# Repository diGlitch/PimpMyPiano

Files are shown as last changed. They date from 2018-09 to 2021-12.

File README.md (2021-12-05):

# PimpMyPiano
## Mbed based interface between Fatar TP44GH keybed and the midi world
---------------------------------------------------------------------------------------------------
Some day the controller board of my StudioLogic SL990Pro stopped working. Instead of buying a whole new masterkeybard I though "why not building one my self and reusing the high quality Fata TP44GH keybed in there". What had to be done was to read out the double button matrix (two buttons/sensors for each note), meassuring the time between two button presses and convert this data into midi commands after about a year I ended up with a Mbed based interface between a Fatar TP44GH keybed and the midi world.

## How to make it work || Underconstruction
These instructions will get you a copy of the project up and running on your local machine for development and testing purposes. See deployment for notes on how to deploy the project on a live system.

There are two parts: The software and the hardware.

### Prerequisites || Underconstruction
What things you need to install the software and how to install them

You will need ...:
* an ARM MBED ready board. I used the [NUCLEO-F411RE](https://os.mbed.com/platforms/ST-Nucleo-F411RE/) from ST. I guess the 100Mhz are a bit overkill so assume that something slower with similar pinout would do.
* hardware that connects the Nucleo with the Button Matrix of the piano. See Hardware folder for schematic and other hardware related details such as a part list.
* software that runs on the Nucleo. You can find the [PlatformIO](http://platformio.org) project in the src folder. Just clone the repo or download scr folder as ZIP and open "PimpMyPiano" folder in platformIO.

## Build With
* [MBED OS](https://www.mbed.com/en/platform/mbed-os/)
* [PlatformIO](http://platformio.org) extension for [VSCode](https://code.visualstudio.com/)

## Contributing || Underconstruction

### What is there to be improved
* Overall code base in terms of speed

## Authors
* **Jeremy Constantin Börker** - *Initial and so far all the work* - [diGlitch](https://github.com/diGlitch)

## License
This project is licensed under the GNU General Public License v3.0 - see the [LICENSE](LICENSE) file for details

## Acknowledgments
* Francois Best's Mbed MIDI Library for Arduino ported by Hiroshi Suga
* YoongHM's Mbed shift register library
* Processing for the mapping formular

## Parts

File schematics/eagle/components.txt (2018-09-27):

Main Components:
Fatar TP44GH
ST NUCLEO-F411RE
2x Shift Register SN74HC595N
Resistor
Resistor
Resistor

Others
DIN 5 Pin MIDI Socket

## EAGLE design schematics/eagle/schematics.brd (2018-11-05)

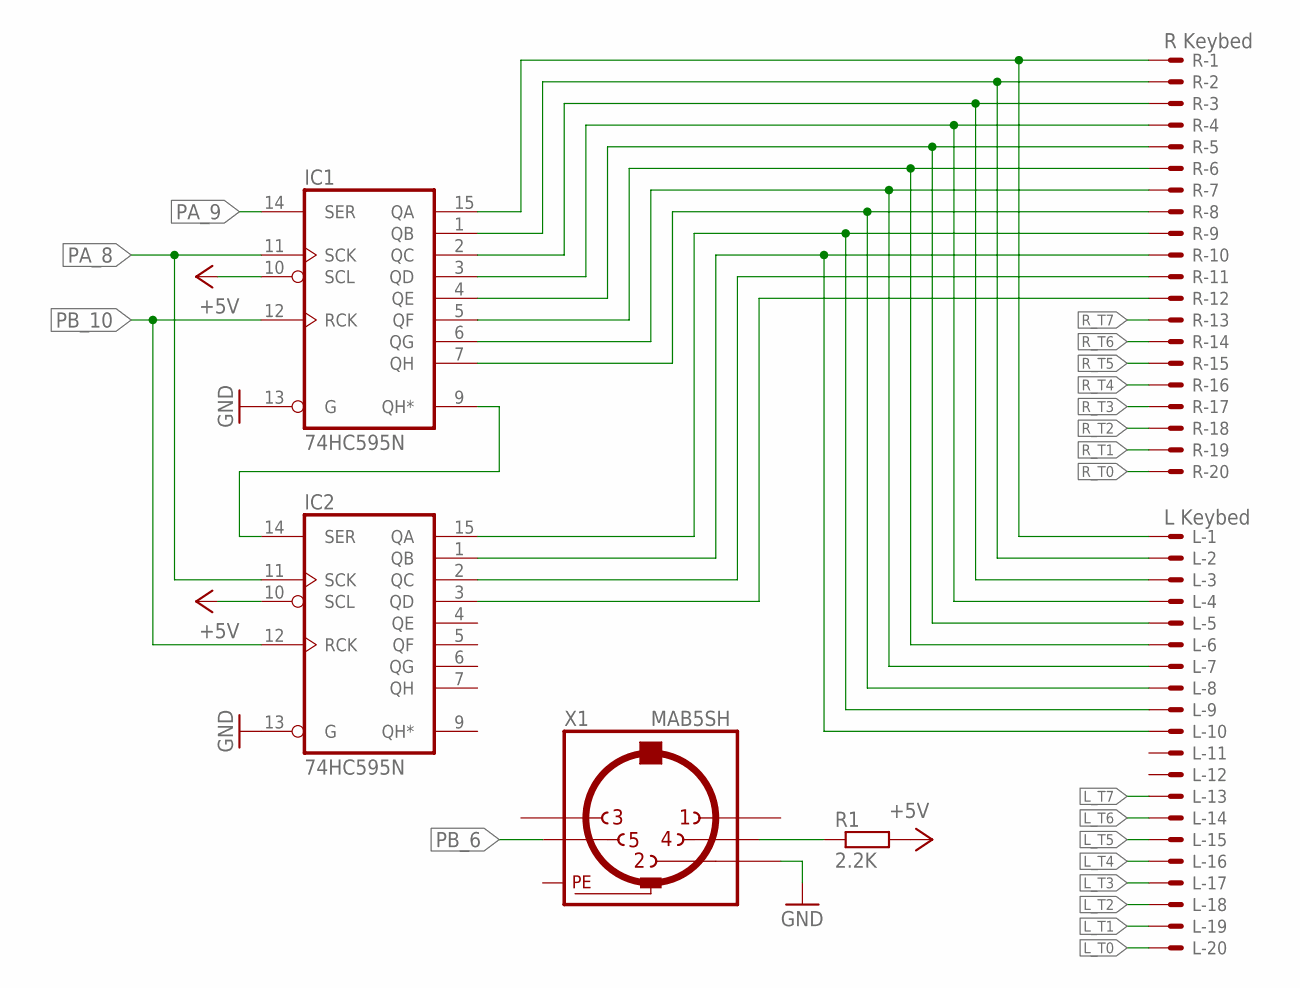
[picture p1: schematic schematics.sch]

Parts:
IC1, IC2: 74HC595N; DIL16
L: L Keybed; 5566-20
R: R Keybed; 5566-20
R1: 2.2K; 0207/10
X1: MAB5SH

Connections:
+5V: IC1.10 (SCL), IC2.10 (SCL), R1.2
GND: IC1.8 (GND), IC1.13 (G), IC2.8 (GND), IC2.13 (G), X1.2
L_T0: L.20
L_T1: L.19
L_T2: L.18
L_T3: L.17
L_T4: L.16
L_T5: L.15
L_T6: L.14
L_T7: L.13
unnamed: IC1.15 (QA), L.1, R.1
unnamed: IC1.1 (QB), L.2, R.2
unnamed: IC1.2 (QC), L.3, R.3
unnamed: IC1.3 (QD), L.4, R.4
unnamed: IC1.4 (QE), L.5, R.5
unnamed: IC1.5 (QF), L.6, R.6
unnamed: IC1.6 (QG), L.7, R.7
unnamed: IC1.7 (QH), L.8, R.8
unnamed: IC2.15 (QA), L.9, R.9
unnamed: IC2.1 (QB), L.10, R.10
unnamed: IC2.2 (QC), R.11
unnamed: IC2.3 (QD), R.12
unnamed: IC1.9 (QH*), IC2.14 (SER)
unnamed: R1.1, X1.4
PA_8: IC1.12 (RCK), IC2.12 (RCK)
PA_9: IC1.14 (SER)
PB_6: X1.5
PB_10: IC1.11 (SCK), IC2.11 (SCK)
PE: X1.PE, X1.PE@ (PE)
R_T0: R.20
R_T1: R.19
R_T2: R.18
R_T3: R.17
R_T4: R.16
R_T5: R.15
R_T6: R.14
R_T7: R.13
VCC: IC1.16 (VCC), IC2.16 (VCC)

Board: 2 copper layers, 6 parts (0 on the bottom side), 20 nets, no tracks yet.

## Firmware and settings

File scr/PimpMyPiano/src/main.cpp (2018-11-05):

/*
<PimpMyPiano - Mbed based interface between a Fatar TP44GH keybed and the midi world.>
Copyright (C) 2018  Jeremy Constantin Börker aka diGlitch

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
You should have received a copy of the GNU General Public License
along with this program.  If not, see <https://www.gnu.org/licenses/>.
*/

// Special Thanks to: Johannes Löwe, Codruta Lugoj


#include "mbed.h"
#include "MIDI.h"
#include <cmath>
#include "PianoKey.h"
#include "ShiftReg.h"

MIDI midi(PB_6, PA_10); // Serail2
Serial pc(USBTX, USBRX); // tx, rx
InterruptIn btn(USER_BUTTON);
DigitalOut led(LED1);

ShiftReg   HC595(PA_9, PA_8, PB_10);
int regCounter = 0;

DigitalIn tl_1(PC_10);
DigitalIn tl_2(PC_12);
DigitalIn tl_3(PA_13);
DigitalIn tl_4(PA_14);
DigitalIn tl_5(PA_15);
DigitalIn tl_6(PB_7);
DigitalIn tl_7(PC_2);
DigitalIn tl_8(PC_3);

DigitalIn tr_1(PC_11);
DigitalIn tr_2(PD_2);
DigitalIn tr_3(PA_0);
DigitalIn tr_4(PA_1);
DigitalIn tr_5(PA_4);
DigitalIn tr_6(PB_0);
DigitalIn tr_7(PC_1);
DigitalIn tr_8(PC_0);

const int DELAY = 05; // time delay to set output register

// set t pins as pullup inputs.
// set mk5 and br5 to 0 to read it t
PianoKey A_0(21);
PianoKey Asharp_0(22);
PianoKey B_0(23);
PianoKey C_1(24);
PianoKey Csharp_1(25);
PianoKey D_1(26);
PianoKey Dsharp_1(27);
PianoKey E_1(28);
PianoKey F_1(29);
PianoKey Fsharp_1(30);
PianoKey G_1(31);
PianoKey Gsharp_1(32);
PianoKey A_1(33);
PianoKey Asharp_1(34);
PianoKey B_1(35);
PianoKey C_2(36);
PianoKey Csharp_2(37);
PianoKey D_2(38);
PianoKey Dsharp_2(39);
PianoKey E_2(40);
PianoKey F_2(41);
PianoKey Fsharp_2(42);
PianoKey G_2(43);
PianoKey Gsharp_2(44);
PianoKey A_2(45);
PianoKey Asharp_2(46);
PianoKey B_2(47);
PianoKey C_3(48);
PianoKey Csharp_3(49);
PianoKey D_3(50);
PianoKey Dsharp_3(51);
PianoKey E_3(52);
PianoKey F_3(53);
PianoKey Fsharp_3(54);
PianoKey G_3(55);
PianoKey Gsharp_3(56);
PianoKey A_3(57);
PianoKey Asharp_3(58);
PianoKey B_3(59);
PianoKey C_4(60);

PianoKey Csharp_4(61);
PianoKey D_4(62);
PianoKey Dsharp_4(63);
PianoKey E_4(64);
PianoKey F_4(65);
PianoKey Fsharp_4(66);
PianoKey G_4(67);
PianoKey Gsharp_4(68);
PianoKey A_4(69);
PianoKey Asharp_4(70);
PianoKey B_4(71);
PianoKey C_5(72);
PianoKey Csharp_5(73);
PianoKey D_5(74);
PianoKey Dsharp_5(75);
PianoKey E_5(76);
PianoKey F_5(77);
PianoKey Fsharp_5(78);
PianoKey G_5(79);
PianoKey Gsharp_5(80);
PianoKey A_5(81);
PianoKey Asharp_5(82);
PianoKey B_5(83);
PianoKey C_6(84);
PianoKey Csharp_6(85);
PianoKey D_6(86);
PianoKey Dsharp_6(87);
PianoKey E_6(88);
PianoKey F_6(89);
PianoKey Fsharp_6(90);
PianoKey G_6(91);
PianoKey Gsharp_6(92);
PianoKey A_6(93);
PianoKey Asharp_6(94);
PianoKey B_6(95);
PianoKey C_7(96);
PianoKey Csharp_7(97);
PianoKey D_7(98);
PianoKey Dsharp_7(99);
PianoKey E_7(100);
PianoKey F_7(101);
PianoKey Fsharp_7(102);
PianoKey G_7(103);
PianoKey Gsharp_7(104);
PianoKey A_7(105);
PianoKey Asharp_7(106);
PianoKey B_7(107);
PianoKey C_8(108);


void buttonOn()   // midi test
{
    pc.printf("Button pressed\n");
    midi.sendNoteOn(60, 127, 1);
}

void buttonOff()   // midi test
{
    pc.printf("Button released\n");
    midi.sendNoteOff(60, 127, 1);
}

void readInput()
{
    if (tl_1.read() == 0) {
            led = 1;
        } else {
            led = 0;
        }
        
    if (regCounter == 1) {
        if (tr_1.read() == 0) {
            A_0.brPressed();
        } else {
            A_0.brReleased();
        }
        if (tr_2.read() == 0) {
            Asharp_0.brPressed();
        } else {
            Asharp_0.brReleased();
        }
        if (tr_3.read() == 0) {
            B_0.brPressed();
        } else {
            B_0.brReleased();
        }
        if (tr_4.read() == 0) {
            C_1.brPressed();
        } else {
            C_1.brReleased();
        }
        if (tr_5.read() == 0) {
            Csharp_1.brPressed();
        } else {
            Csharp_1.brReleased();
        }
        if (tr_6.read() == 0) {
            D_1.brPressed();
        } else {
            D_1.brReleased();
        }
        if (tr_7.read() == 0) {
            Dsharp_1.brPressed();
        } else {
            Dsharp_1.brReleased();
        }
        if (tr_8.read() == 0) {
            E_1.brPressed();
        } else {
            E_1.brReleased();
        }
        if (tl_1.read() == 0) {
            Csharp_4.brPressed();
        } else {
            Csharp_4.brReleased();
        }
        if (tl_2.read() == 0) {
            D_4.brPressed();
        } else {
            D_4.brReleased();
        }
        if (tl_3.read() == 0) {
            Dsharp_4.brPressed();
        } else {
            Dsharp_4.brReleased();
        }
        if (tl_4.read() == 0) {
            E_4.brPressed();
        } else {
            E_4.brReleased();
        }
        if (tl_5.read() == 0) {
            F_4.brPressed();
        } else {
            F_4.brReleased();
        }
        if (tl_6.read() == 0) {
            Fsharp_4.brPressed();
        } else {
            Fsharp_4.brReleased();
        }
        if (tl_7.read() == 0) {
            G_4.brPressed();
        } else {
            G_4.brReleased();
        }
        if (tl_8.read() == 0) {
            Gsharp_4.brPressed();
        } else {
            Gsharp_4.brReleased();
        }
    }
    if (regCounter == 2) {
        if (tr_1.read() == 0) {
            A_0.mkPressed();
        } else {
            A_0.mkReleased();
        }
        if (tr_2.read() == 0) {
            Asharp_0.mkPressed();
        } else {
            Asharp_0.mkReleased();
        }
        if (tr_3.read() == 0) {
            B_0.mkPressed();
        } else {
            B_0.mkReleased();
        }
        if (tr_4.read() == 0) {
            C_1.mkPressed();
        } else {
            C_1.mkReleased();
        }
        if (tr_5.read() == 0) {
            Csharp_1.mkPressed();
        } else {
            Csharp_1.mkReleased();
        }
        if (tr_6.read() == 0) {
            D_1.mkPressed();
        } else {
            D_1.mkReleased();
        }
        if (tr_7.read() == 0) {
            Dsharp_1.mkPressed();
        } else {
            Dsharp_1.mkReleased();
        }
        if (tr_8.read() == 0) {
            E_1.mkPressed();
        } else {
            E_1.mkReleased();
        }
        if (tl_1.read() == 0) {
            Csharp_4.mkPressed();
        } else {
            Csharp_4.mkReleased();
        }
        if (tl_2.read() == 0) {
            D_4.mkPressed();
        } else {
            D_4.mkReleased();
        }
        if (tl_3.read() == 0) {
            Dsharp_4.mkPressed();
        } else {
            Dsharp_4.mkReleased();
        }
        if (tl_4.read() == 0) {
            E_4.mkPressed();
        } else {
            E_4.mkReleased();
        }
        if (tl_5.read() == 0) {
            F_4.mkPressed();
        } else {
            F_4.mkReleased();
        }
        if (tl_6.read() == 0) {
            Fsharp_4.mkPressed();
        } else {
            Fsharp_4.mkReleased();
        }
        if (tl_7.read() == 0) {
            G_4.mkPressed();
        } else {
            G_4.mkReleased();
        }
        if (tl_8.read() == 0) {
            Gsharp_4.mkPressed();
        } else {
            Gsharp_4.mkReleased();
        }
    }

    if (regCounter == 3) {
        if (tr_1.read() == 0) {
            F_1.brPressed();
        } else {
            F_1.brReleased();
        }
        if (tr_2.read() == 0) {
            Fsharp_1.brPressed();
        } else {
            Fsharp_1.brReleased();
        }
        if (tr_3.read() == 0) {
            G_1.brPressed();
        } else {
            G_1.brReleased();
        }
        if (tr_4.read() == 0) {
            Gsharp_1.brPressed();
        } else {
            Gsharp_1.brReleased();
        }
        if (tr_5.read() == 0) {
            A_1.brPressed();
        } else {
            A_1.brReleased();
        }
        if (tr_6.read() == 0) {
            Asharp_1.brPressed();
        } else {
            Asharp_1.brReleased();
        }
        if (tr_7.read() == 0) {
            B_1.brPressed();
        } else {
            B_1.brReleased();
        }
        if (tr_8.read() == 0) {
            C_2.brPressed();
        } else {
            C_2.brReleased();
        }
        if (tl_1.read() == 0) {
            A_4.brPressed();
        } else {
            A_4.brReleased();
        }
        if (tl_2.read() == 0) {
            Asharp_4.brPressed();
        } else {
            Asharp_4.brReleased();
        }
        if (tl_3.read() == 0) {
            B_4.brPressed();
        } else {
            B_4.brReleased();
        }
        if (tl_4.read() == 0) {
            C_5.brPressed();
        } else {
            C_5.brReleased();
        }
        if (tl_5.read() == 0) {
            Csharp_5.brPressed();
        } else {
            Csharp_5.brReleased();
        }
        if (tl_6.read() == 0) {
            D_5.brPressed();
        } else {
            D_5.brReleased();
        }
        if (tl_7.read() == 0) {
            Dsharp_5.brPressed();
        } else {
            Dsharp_5.brReleased();
        }
        if (tl_8.read() == 0) {
            E_5.brPressed();
        } else {
            E_5.brReleased();
        }
    }
    if (regCounter == 4) {
        if (tr_1.read() == 0) {
            F_1.mkPressed();
        } else {
            F_1.mkReleased();
        }
        if (tr_2.read() == 0) {
            Fsharp_1.mkPressed();
        } else {
            Fsharp_1.mkReleased();
        }
        if (tr_3.read() == 0) {
            G_1.mkPressed();
        } else {
            G_1.mkReleased();
        }
        if (tr_4.read() == 0) {
            Gsharp_1.mkPressed();
        } else {
            Gsharp_1.mkReleased();
        }
        if (tr_5.read() == 0) {
            A_1.mkPressed();
        } else {
            A_1.mkReleased();
        }
        if (tr_6.read() == 0) {
            Asharp_1.mkPressed();
        } else {
            Asharp_1.mkReleased();
        }
        if (tr_7.read() == 0) {
            B_1.mkPressed();
        } else {
            B_1.mkReleased();
        }
        if (tr_8.read() == 0) {
            C_2.mkPressed();
        } else {
            C_2.mkReleased();
        }
        if (tl_1.read() == 0) {
            A_4.mkPressed();
        } else {
            A_4.mkReleased();
        }
        if (tl_2.read() == 0) {
            Asharp_4.mkPressed();
        } else {
            Asharp_4.mkReleased();
        }
        if (tl_3.read() == 0) {
            B_4.mkPressed();
        } else {
            B_4.mkReleased();
        }
        if (tl_4.read() == 0) {
            C_5.mkPressed();
        } else {
            C_5.mkReleased();
        }
        if (tl_5.read() == 0) {
            Csharp_5.mkPressed();
        } else {
            Csharp_5.mkReleased();
        }
        if (tl_6.read() == 0) {
            D_5.mkPressed();
        } else {
            D_5.mkReleased();
        }
        if (tl_7.read() == 0) {
            Dsharp_5.mkPressed();
        } else {
            Dsharp_5.mkReleased();
        }
        if (tl_8.read() == 0) {
            E_5.mkPressed();
        } else {
            E_5.mkReleased();
        }
    }

    if (regCounter == 5) {
        if (tr_1.read() == 0) {
            Csharp_2.brPressed();
        } else {
            Csharp_2.brReleased();
        }
        if (tr_2.read() == 0) {
            D_2.brPressed();
        } else {
            D_2.brReleased();
        }
        if (tr_3.read() == 0) {
            Dsharp_2.brPressed();
        } else {
            Dsharp_2.brReleased();
        }
        if (tr_4.read() == 0) {
            E_2.brPressed();
        } else {
            E_2.brReleased();
        }
        if (tr_5.read() == 0) {
            F_2.brPressed();
        } else {
            F_2.brReleased();
        }
        if (tr_6.read() == 0) {
            Fsharp_2.brPressed();
        } else {
            Fsharp_2.brReleased();
        }
        if (tr_7.read() == 0) {
            G_2.brPressed();
        } else {
            G_2.brReleased();
        }
        if (tr_8.read() == 0) {
            Gsharp_2.brPressed();
        } else {
            Gsharp_2.brReleased();
        }
        if (tl_1.read() == 0) {
            F_5.brPressed();
        } else {
            F_5.brReleased();
        }
        if (tl_2.read() == 0) {
            Fsharp_5.brPressed();
        } else {
            Fsharp_5.brReleased();
        }
        if (tl_3.read() == 0) {
            G_5.brPressed();
        } else {
            G_5.brReleased();
        }
        if (tl_4.read() == 0) {
            Gsharp_5.brPressed();
        } else {
            Gsharp_5.brReleased();
        }
        if (tl_5.read() == 0) {
            A_5.brPressed();
        } else {
            A_5.brReleased();
        }
        if (tl_6.read() == 0) {
            Asharp_5.brPressed();
        } else {
            Asharp_5.brReleased();
        }
        if (tl_7.read() == 0) {
            B_5.brPressed();
        } else {
            B_5.brReleased();
        }
        if (tl_8.read() == 0) {
            C_6.brPressed();
        } else {
            C_6.brReleased();
        }
    }
    if (regCounter == 6) {
        if (tr_1.read() == 0) {
            Csharp_2.mkPressed();
        } else {
            Csharp_2.mkReleased();
        }
        if (tr_2.read() == 0) {
            D_2.mkPressed();
        } else {
            D_2.mkReleased();
        }
        if (tr_3.read() == 0) {
            Dsharp_2.mkPressed();
        } else {
            Dsharp_2.mkReleased();
        }
        if (tr_4.read() == 0) {
            E_2.mkPressed();
        } else {
            E_2.mkReleased();
        }
        if (tr_5.read() == 0) {
            F_2.mkPressed();
        } else {
            F_2.mkReleased();
        }
        if (tr_6.read() == 0) {
            Fsharp_2.mkPressed();
        } else {
            Fsharp_2.mkReleased();
        }
        if (tr_7.read() == 0) {
            G_2.mkPressed();
        } else {
            G_2.mkReleased();
        }
        if (tr_8.read() == 0) {
            Gsharp_2.mkPressed();
        } else {
            Gsharp_2.mkReleased();
        }
        if (tl_1.read() == 0) {
            F_5.mkPressed();
        } else {
            F_5.mkReleased();
        }
        if (tl_2.read() == 0) {
            Fsharp_5.mkPressed();
        } else {
            Fsharp_5.mkReleased();
        }
        if (tl_3.read() == 0) {
            G_5.mkPressed();
        } else {
            G_5.mkReleased();
        }
        if (tl_4.read() == 0) {
            Gsharp_5.mkPressed();
        } else {
            Gsharp_5.mkReleased();
        }
        if (tl_5.read() == 0) {
            A_5.mkPressed();
        } else {
            A_5.mkReleased();
        }
        if (tl_6.read() == 0) {
            Asharp_5.mkPressed();
        } else {
            Asharp_5.mkReleased();
        }
        if (tl_7.read() == 0) {
            B_5.mkPressed();
        } else {
            B_5.mkReleased();
        }
        if (tl_8.read() == 0) {
            C_6.mkPressed();
        } else {
            C_6.mkReleased();
        }
    }
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
int main()
{
    pc.printf("\nHello World\n\n");
    midi.begin(MIDI_CHANNEL_OMNI);
    //Init ShiftRegister
    for(int i = 0; i < 16; i++) {
        HC595.ShiftBit(1);
    }
    HC595.Latch();
    // midi test
    btn.rise(&buttonOff);
    btn.fall(&buttonOn);

    tl_1.mode(PullUp);
    tl_2.mode(PullUp);
    tl_3.mode(PullUp);
    tl_4.mode(PullUp);
    tl_5.mode(PullUp);
    tl_6.mode(PullUp);
    tl_7.mode(PullUp);
    tl_8.mode(PullUp);
    
    tr_1.mode(PullUp);
    tr_2.mode(PullUp);
    tr_3.mode(PullUp);
    tr_4.mode(PullUp);
    tr_5.mode(PullUp);
    tr_6.mode(PullUp);
    tr_7.mode(PullUp);
    tr_8.mode(PullUp);

    while(1) {
        regNext();
        wait_us(DELAY);
        readInput();
    }
}

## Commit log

2018-09-27 Switch to PlatformIO
2018-09-27 Added VelocityDevNotebook
2018-10-01 Added new formula to generate velocity 4 and implemented it
2018-10-04 Added sliders and changed layout of Velocity Curve Designer
2018-10-04 added printing and comments in Velo designer, tested new Velocity curves
2018-11-05 Started with creating the circuit in eagle and fritzing
    [circuitDiagram.fzz, schematics.brd, schematics.sch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]
2018-11-23 First java velocity curve designer commit. VeloCurveDesigner 2000

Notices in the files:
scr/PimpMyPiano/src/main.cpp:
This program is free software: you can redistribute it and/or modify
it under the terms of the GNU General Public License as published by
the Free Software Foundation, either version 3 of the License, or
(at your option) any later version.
